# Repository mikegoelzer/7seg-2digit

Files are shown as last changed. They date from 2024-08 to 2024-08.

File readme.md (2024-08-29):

# Two Digit 7-Segment Display

This repository contains the design files for a 2-digit 7-segment display PMOD, modeled after the Digilent PMOD design but without a dual-row Dupont male header pinout. The display is designed for 3.3V operation and uses multiplexing to control both digits using only 8 GPIOs (7 for segments, one for left/right digit select).

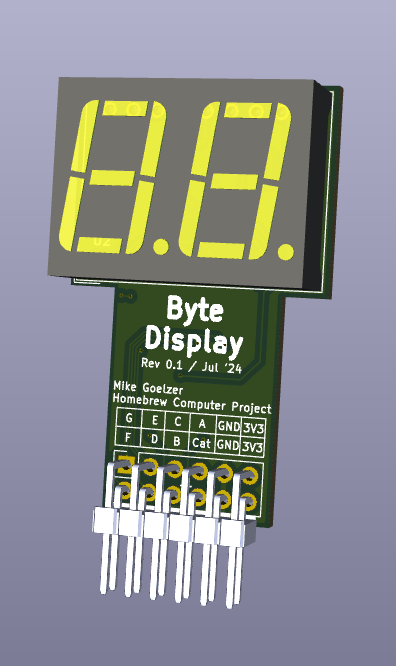
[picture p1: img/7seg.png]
3D Rendering of the 7-Segment Display printed circuit board


## Features

- 2-digit 7-segment display
- 3.3V operation
- Multiplexed design (8 GPIOs control both digits)

## Schematic

The schematic for this design can be found in the [docs/schematic.pdf](docs/schematic.pdf) file.

## Repository Structure

- `7Seg-Kicad/`: KiCad project files
- `bom/`: Excel sheet with Digikey/Mouser part numbers
- `docs/`: Documentation, including the schematic PDF
- `img/`: Images, including the 3D rendering
- `Parts/`: Parts imported into Kicad project

## Usage

This PCB can be used with any FPGA or microcontroller board, although it uses a non-standard pinout (for PMODs). The multiplexed design allows for efficient control of both digits using minimal GPIO pins.

## License

[GPLv3](https://www.gnu.org/licenses/gpl-3.0.en.html)

## Contributing

We welcome contributions to improve this design. Please feel free to submit issues or pull requests.

## Acknowledgements

This design is inspired by the [Digilent PMOD 7-segment display](https://digilent.com/shop/pmod-ssd-seven-segment-display/) but has been modified to fit a custom board and does not conform to the normal PMOD pinout.

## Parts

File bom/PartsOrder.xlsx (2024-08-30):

Desc | Parts | Actual Qty | Order Qty | Price | Subtotal | In basket? | Ordered? | Vendor URL | Mfgr PN | Notes | Digikey | Adafruit | Mouser | Sparkfun
Carrier Board: Hex Digits 7-segment
# of boards | 3
Bright red 2x7seg (DC56-11SURKWA) | U2 | 1 | 2 | 3.33 | $6.66 | ✅ | ❌ | https://www.digikey.com/en/products/detail/kingbright/DC56-11SURKWA/4098431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 | DC56-11SURKWA
NL27WZ14DFT2G dual inverter in SC-88 package | U1 | 1 | 3 | 0.32 | $0.96 | ✅ | ❌ | https://www.digikey.com/en/products/detail/onsemi/NL27WZ14DFT2G/920165 | NL27WZ14DFT2G |  | 1
820 resistors, 1206 3216 metric | R1-R8 | 8 | 0 | 0.1 | $0.00 | ✅ | ❌ | https://www.digikey.com/en/products/detail/yageo/RC1206JR-07820RL/729342 |  |  | 1
1k resistors, 1206 3216 metric | R1-R8 (alternate) | 8 | 24 | 0.035 | $0.84 | ✅ |  | https://www.digikey.com/en/products/detail/yageo/RC1206JR-071KL/729186
CAP CER 0.1UF 50V X7R 1206 | C1 | 1 | 0 | 0.19 | $0.00 | ✅ | ❌ | https://www.digikey.com/en/products/detail/yageo/CC1206KRX7R9BB104/302913 |  |  | 1
CAP 1206 25V 10 UF X7R | C2 | 1 | 0 | 0.51 | $0.00 | ✅ | ❌ | https://www.digikey.com/en/products/detail/yageo/cc1206kfx7r8bb106/20376253 |  |  | 1
2x6 right angle male 0.1" header pins | J1 | 1 | 2 | 0.37 | $0.74 | ✅ | ❌ | https://www.digikey.com/en/products/detail/adam-tech/PH2RA-12-UA/9830569 | PH2RA-12-UA |  | 1
Breadboard Breakout
# of boards | 4
6x2 0.1" female receptacle |  | 1 | 4 | 0.83 | $3.32 | ✅ | ❌ | https://www.digikey.com/en/products/detail/sullins-connector-solutions/PPPC062LFBN-RC/810246 | PPPC062LFBN-RC |  | 1
6x1 CONN HEADER VERT 6POS 2.54MM |  | 2 | 10 | 0.34 | $3.40 | ✅ | ❌ | https://www.digikey.com/en/products/detail/w%C3%BCrth-elektronik/61300611121/4846833 | 61300611121 |  | 1
Breadboard Breakout (ULX3S)
# of boards | 2
CONN HDR 40POS 0.1 GOLD PCB 2x20 female | J5 | 1 | 2 | 2.4 | $4.80 | ✅ | ❌ | https://www.digikey.com/en/products/detail/sullins-connector-solutions/PPPC202LFBN-RC/810259 | PPPC202LFBN-RC |  | 1
1x20 male pin headers 2.54mm | J6,J7 | 2 | 4 | 0.47 | $1.88 | ✅ | ❌ | https://www.digikey.com/en/products/detail/sullins-connector-solutions/PRPC020SFAN-RC/2775354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 | PRPC020SFAN-RC |  | 1

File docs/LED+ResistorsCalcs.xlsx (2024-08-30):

7 Segment Options
VCC |  | 3.30 | V
Part |  | Vf * | R | Current (mA) | ucd @ [current] |  | Notes | Digikey | Mouser | Datasheet
DC56-11GWA ** |  | 1.85 | 820 | 1.8 | 1980 |  | ** Used last time; too dim
* At specified current
New Parts & Resistors To Try
 | Color | Vf (at 4mA) | R | Current (mA) | ucd @ [current] | %age incr. brightness
~~DC56-11GWA~~ | ~~Green~~ | ~~1.85~~ | ~~360~~ | ~~4.0~~ | ~~4430.555556~~ | ~~123.7654321%~~ |  | ~~https://www.digikey.com/en/products/detail/kingbright/DC56-11GWA/3084377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 | ~~https://www.mouser.com/ProductDetail/Kingbright/DC56-11GWA?qs=sXafwHSx%252BU%252BFqc2jozM64A%3D%3D~~ | ~~https://www.mouser.com/datasheet/2/216/DC56_11GWA-3085178.pdf~~
DC56-11CGKWA | Bright green | 1.92 | 820 | 1.7 | 5890.243902 | 197.4870658% |  | Not available | Not available | https://www.kingbrightusa.com/images/catalog/SPEC/DC56-11CGKWA.pdf
DC56-11SURKWA | Bright red | 1.78 | 1000 | 1.5 | 12920 | 552.5252525% |  | https://www.digikey.com/en/products/detail/kingbright/DC56-11SURKWA/4098431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 | https://www.mouser.com/ProductDetail/Kingbright/DC56-11SURKWA?qs=2JU0tDl2GZ0YLerPzy77tw%3D%3D | https://www.mouser.com/datasheet/2/216/DC56-11SURKWA-245536.pdf
DC56-51SYKWA | Bright yellow | 1.90 | 1000 | 1.4 | 11900 | 501.010101% |  | Not available | Not available | https://www.mouser.com/datasheet/2/216/DC56-51SYKWA-246230.pdf
~~DC56-11EWA~~ | ~~Red~~ | ~~1.78~~ | ~~360~~ | ~~4.2~~ | ~~3377.777778~~ | ~~70.59483726%~~ |  | ~~https://www.digikey.com/en/products/detail/kingbright/DC56-11EWA/3084376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 | ~~https://www.mouser.com/ProductDetail/Kingbright/DC56-11EWA?qs=SO8VdE%2FgosGvL%2FnJcFkMow%3D%3D~~ | ~~https://www.mouser.com/datasheet/2/216/DC56-11EWA-43385.pdf~~

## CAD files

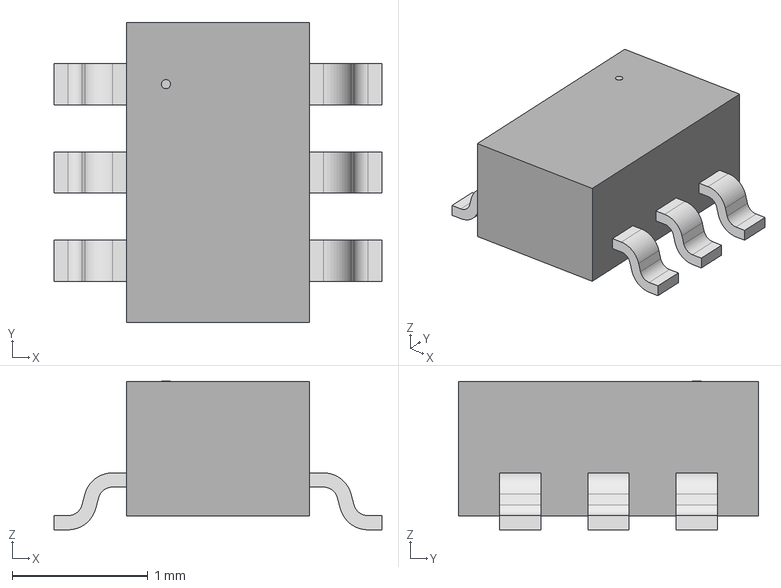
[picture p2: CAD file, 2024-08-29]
Parts/NL27WZ14DFT2G/SC70-6_ONS.step
2.41 x 2.21 x 1.09 mm

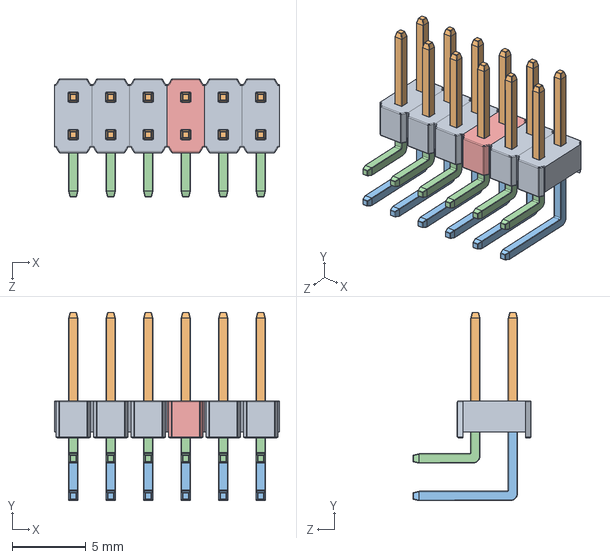
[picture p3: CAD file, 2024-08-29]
Parts/PH2RA-12-UA/PH2RA-12-UA.STEP
15.2 x 12.8 x 8.00 mm

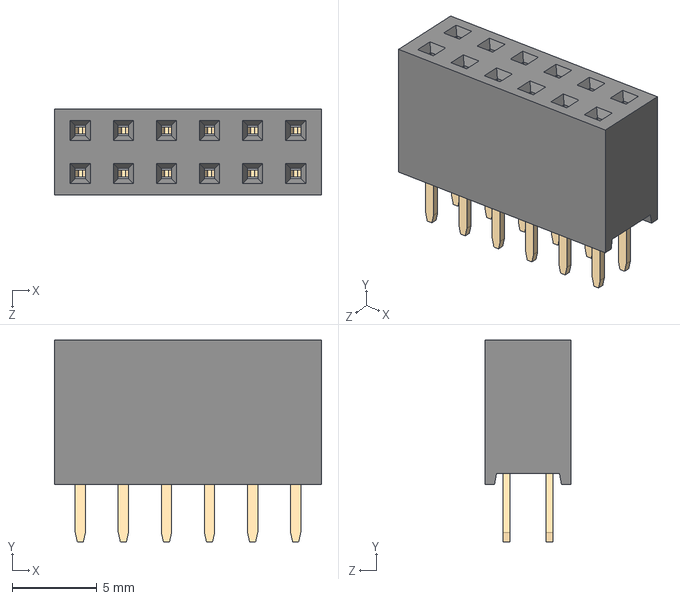
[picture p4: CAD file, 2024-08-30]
Parts/PPPC062LFBN-RC/PPPC062LFBN-RC.STEP
15.7 x 11.9 x 5.08 mm
2 row tin body_06
2 row tin pins x 6

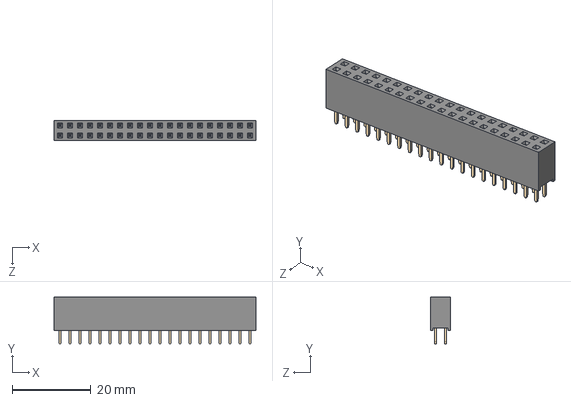
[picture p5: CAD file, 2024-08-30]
Parts/PPPC202LFBN-RC/PPPC202LFBN-RC.step
51.3 x 11.9 x 5.08 mm
2 row tin body_20
2 row tin pins x 20

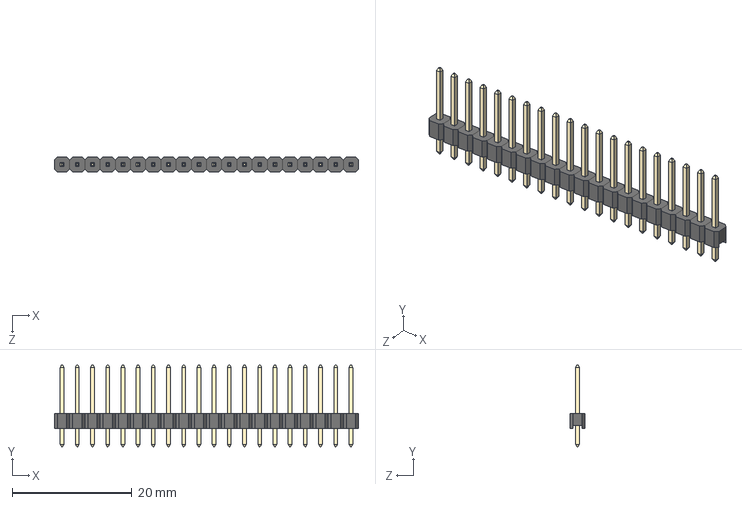
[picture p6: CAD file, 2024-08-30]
Parts/PRPC020SFAN-RC/PRPC020SFAN-RC.STEP
50.8 x 13.7 x 2.54 mm
1 row end bumps format x 20

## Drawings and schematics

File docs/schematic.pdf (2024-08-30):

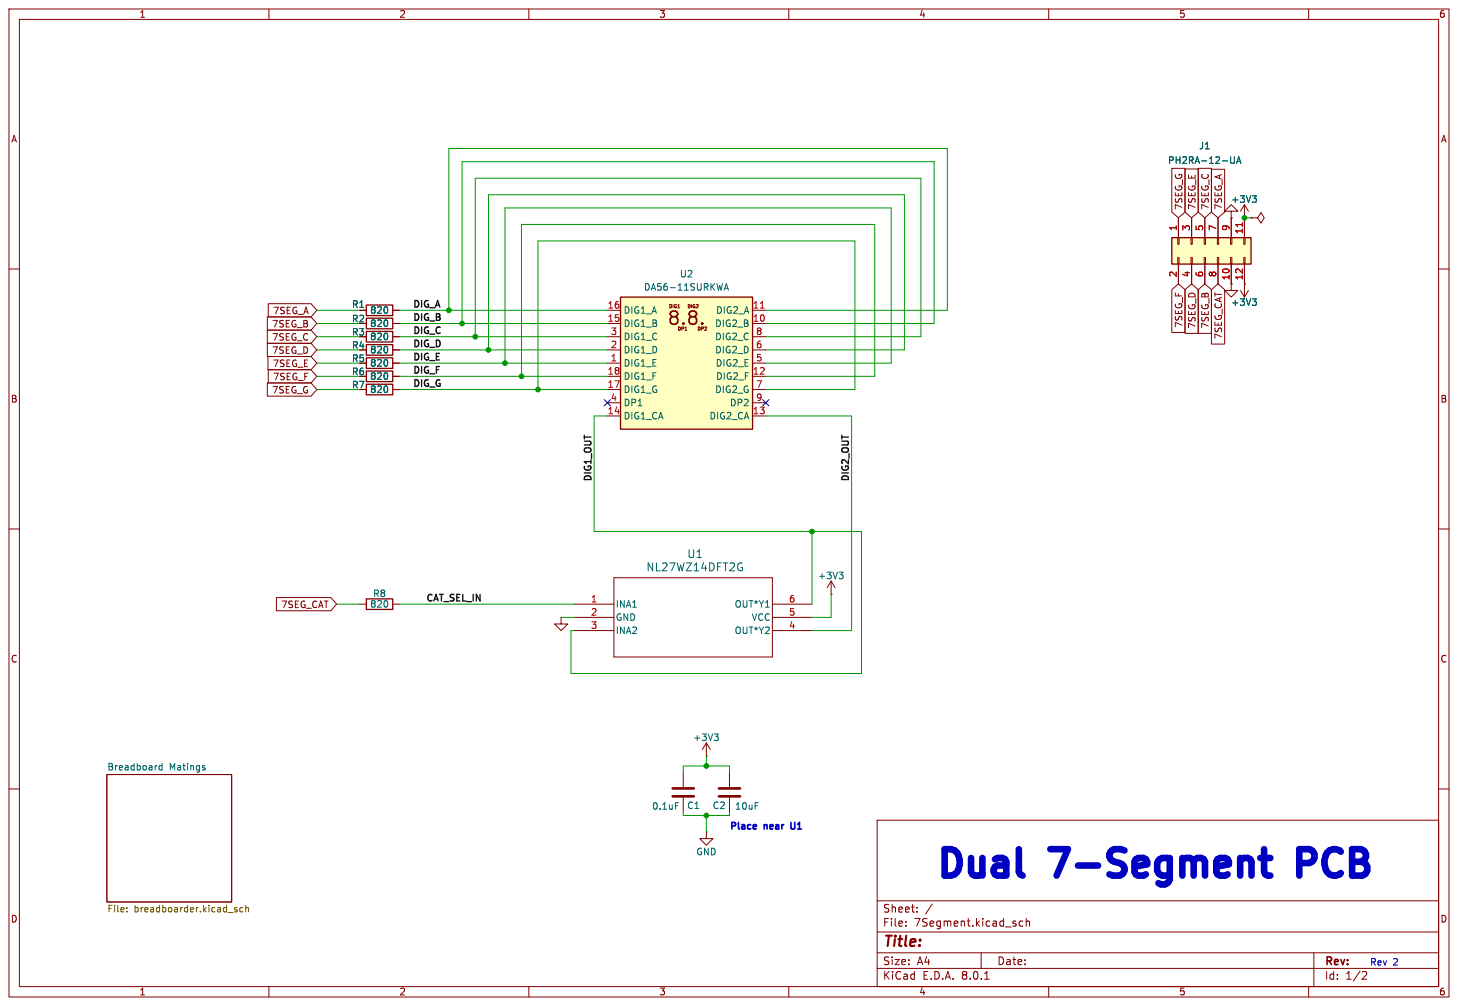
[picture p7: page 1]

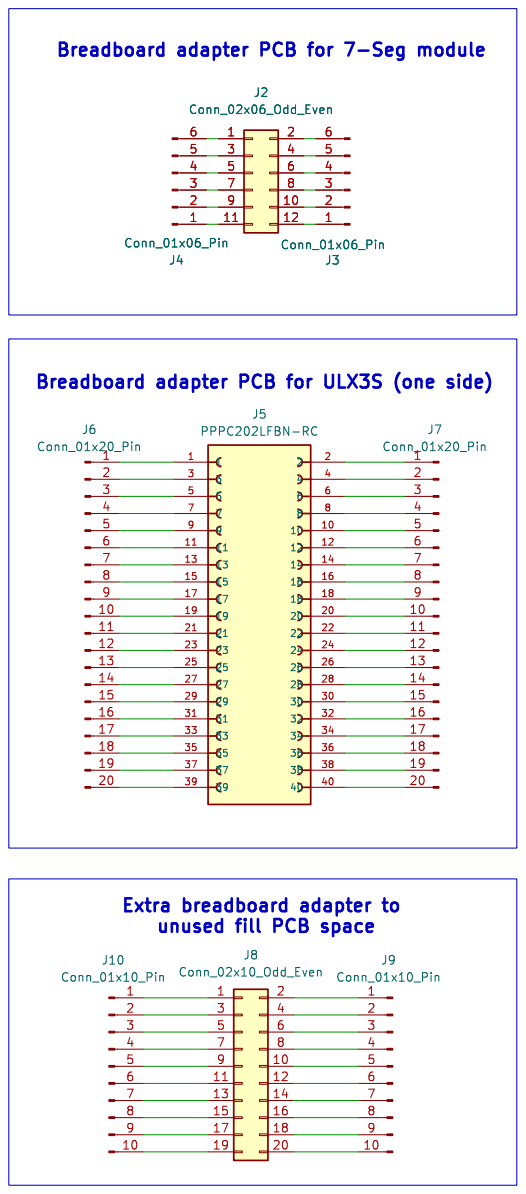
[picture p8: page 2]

Breadboard adapter PCB for ULX3S (one side) J4 Conn_01x06_Pin

Extra breadboard adapter to
unused fill PCB space

Adapter PCBs
(for plugging into breadboards)

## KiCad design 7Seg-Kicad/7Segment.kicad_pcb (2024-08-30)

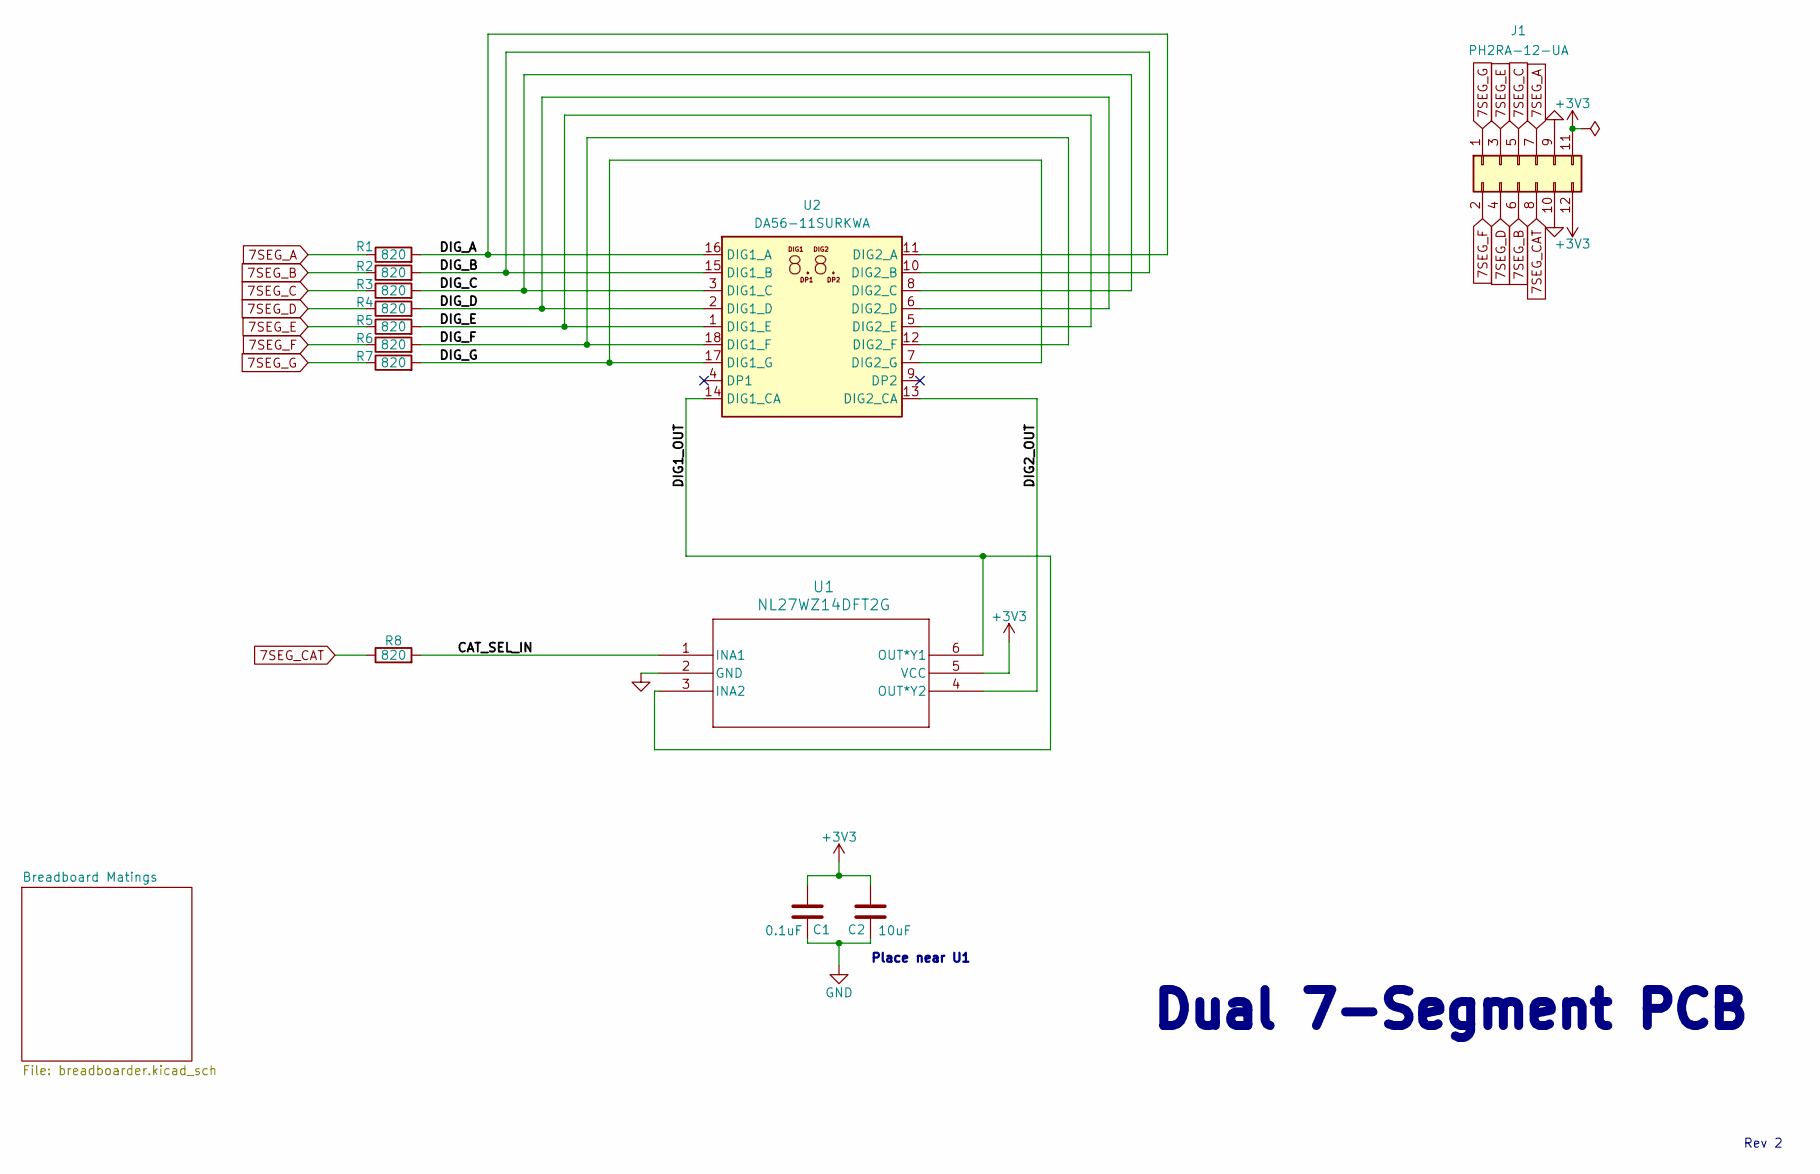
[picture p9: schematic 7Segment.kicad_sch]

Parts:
C1: 0.1uF; C_1206_3216Metric_Pad1.33x1.80mm_HandSolder
C2: 10uF; C_1206_3216Metric_Pad1.33x1.80mm_HandSolder
J1: PH2RA-12-UA; PinSocket_2x06_P2.54mm_Vertical; MPN PH2RA-12-UA
R1, R2, R3, R4, R5, R6, R7, R8: 820; R_1206_3216Metric_Pad1.42x1.75mm_HandSolder
U1: NL27WZ14DFT2G; SC70-6_ONS
U2: DA56-11SURKWA

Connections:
7SEG_A: J1.7, R1.1
7SEG_B: J1.6, R2.1
7SEG_C: J1.5, R3.1
7SEG_CAT: J1.8, R8.1
7SEG_D: J1.4, R4.1
7SEG_E: J1.3, R5.1
7SEG_F: J1.2, R6.1
7SEG_G: J1.1, R7.1
+3V3: C1.2, C2.2, J1.11, J1.12, U1.5 (VCC)
/CAT_SEL_IN: R8.2, U1.1 (INA1)
/DIG1_OUT: U1.3 (INA2), U1.6 (OUT*Y1), U2.14 (DIG1_CA)
/DIG2_OUT: U1.4 (OUT*Y2), U2.13 (DIG2_CA)
/DIG_A: R1.2, U2.11 (DIG2_A), U2.16 (DIG1_A)
/DIG_B: R2.2, U2.10 (DIG2_B), U2.15 (DIG1_B)
/DIG_C: R3.2, U2.3 (DIG1_C), U2.8 (DIG2_C)
/DIG_D: R4.2, U2.2 (DIG1_D), U2.6 (DIG2_D)
/DIG_E: R5.2, U2.1 (DIG1_E), U2.5 (DIG2_E)
/DIG_F: R6.2, U2.12 (DIG2_F), U2.18 (DIG1_F)
/DIG_G: R7.2, U2.7 (DIG2_G), U2.17 (DIG1_G)
GND: C1.1, C2.1, J1.9, J1.10, U1.2 (GND)

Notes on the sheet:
Place near U1
Rev 2
Dual 7-Segment PCB

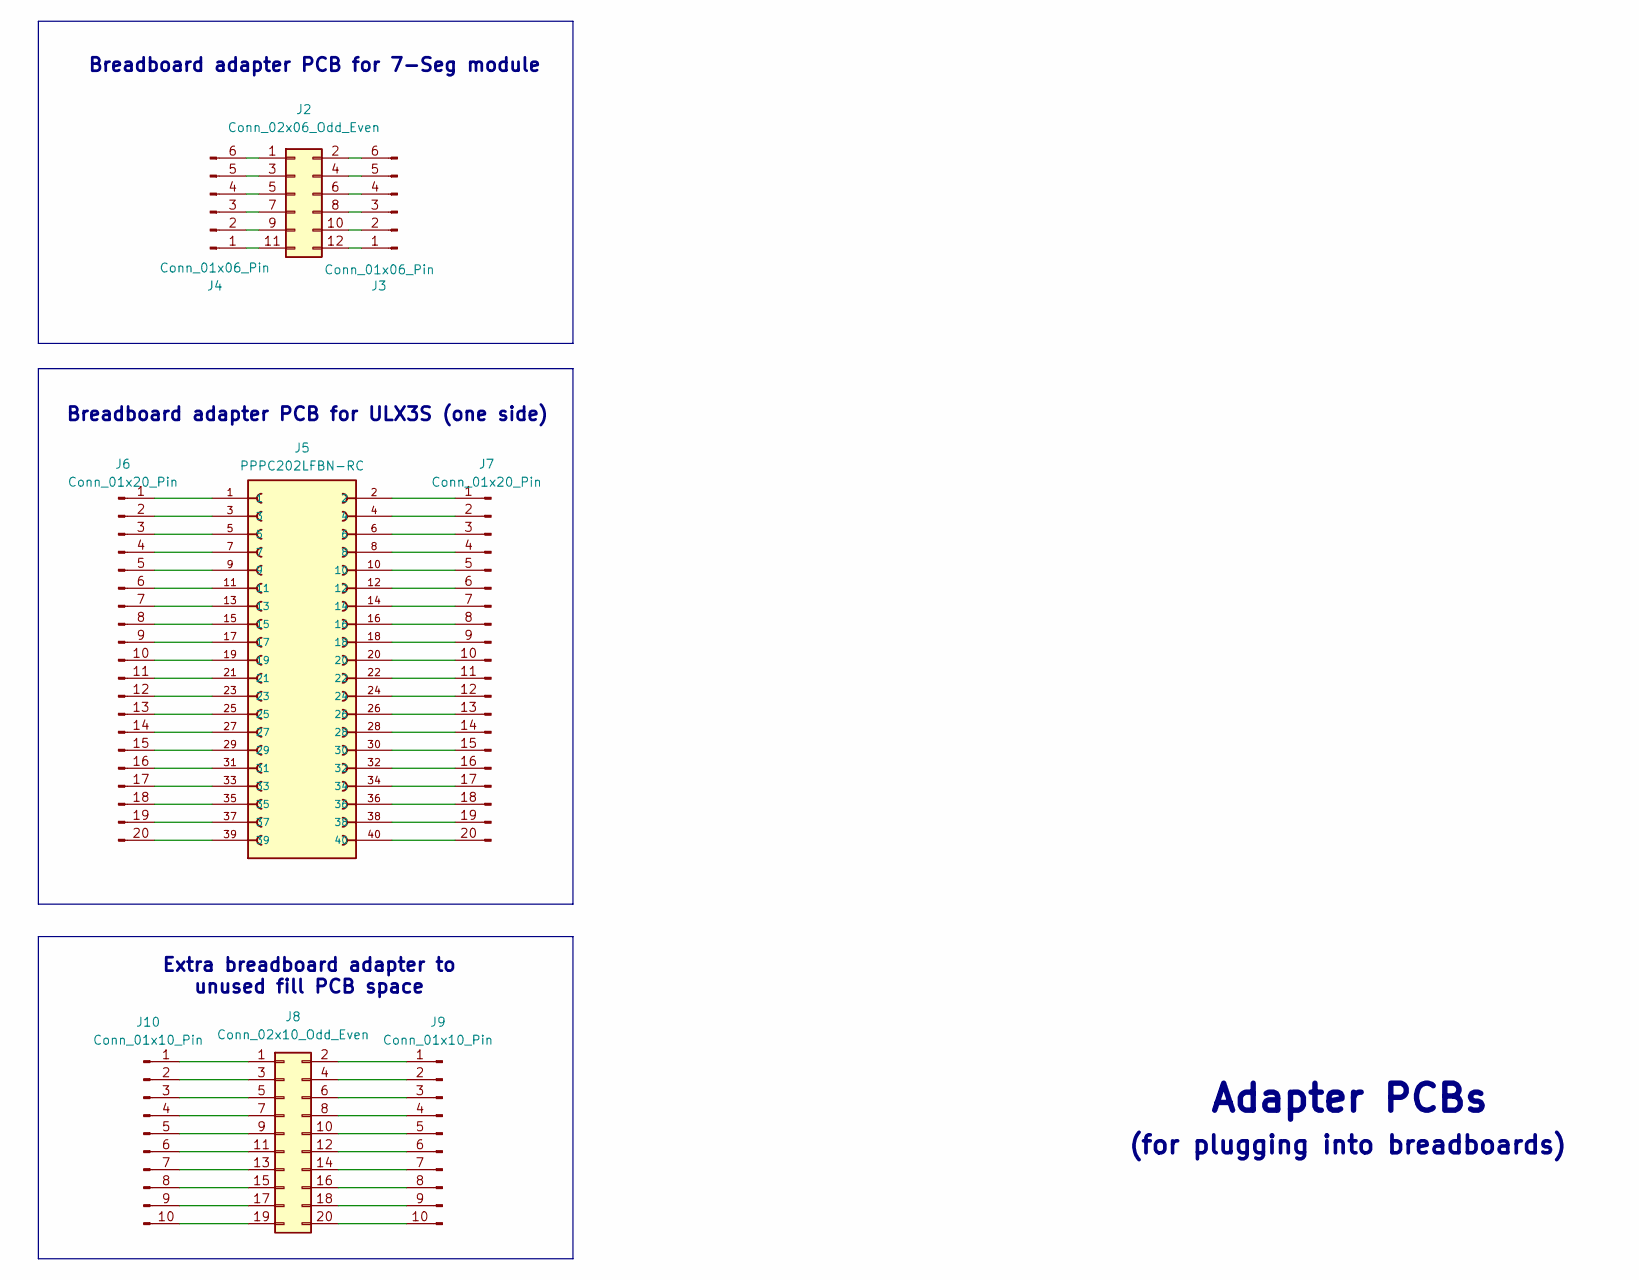
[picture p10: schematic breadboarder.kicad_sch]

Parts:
J2: Conn_02x06_Odd_Even; PinSocket_2x06_P2.54mm_Vertical
J3, J4: Conn_01x06_Pin; PinHeader_1x06_P2.54mm_Vertical
J5: PPPC202LFBN-RC; SULLINS_PPPC202LFBN-RC; PARTREV L
J6, J7: Conn_01x20_Pin; PinHeader_1x20_P2.54mm_Vertical
J8: Conn_02x10_Odd_Even; PinSocket_2x10_P2.54mm_Vertical
J9, J10: Conn_01x10_Pin; PinHeader_1x10_P2.54mm_Vertical

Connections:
unnamed: J2.1, J4.6
unnamed: J2.2, J3.6
unnamed: J2.3, J4.5
unnamed: J2.4, J3.5
unnamed: J2.5, J4.4
unnamed: J2.6, J3.4
unnamed: J2.7, J4.3
unnamed: J2.8, J3.3
unnamed: J2.9, J4.2
unnamed: J2.10, J3.2
unnamed: J2.11, J4.1
unnamed: J2.12, J3.1
unnamed: J5.1, J6.1
unnamed: J5.3, J6.2
unnamed: J5.5, J6.3
unnamed: J5.7, J6.4
unnamed: J5.9, J6.5
unnamed: J5.11, J6.6
unnamed: J5.13, J6.7
unnamed: J5.15, J6.8
unnamed: J5.17, J6.9
unnamed: J5.19, J6.10
unnamed: J5.21, J6.11
unnamed: J5.23, J6.12
unnamed: J5.25, J6.13
unnamed: J5.27, J6.14
unnamed: J5.29, J6.15
unnamed: J5.31, J6.16
unnamed: J5.33, J6.17
unnamed: J5.35, J6.18
unnamed: J5.37, J6.19
unnamed: J5.39, J6.20
unnamed: J5.2, J7.1
unnamed: J5.4, J7.2
unnamed: J5.6, J7.3
unnamed: J5.8, J7.4
unnamed: J5.10, J7.5
unnamed: J5.12, J7.6
unnamed: J5.14, J7.7
unnamed: J5.16, J7.8
unnamed: J5.18, J7.9
unnamed: J5.20, J7.10
unnamed: J5.22, J7.11
unnamed: J5.24, J7.12
unnamed: J5.26, J7.13
unnamed: J5.28, J7.14
unnamed: J5.30, J7.15
unnamed: J5.32, J7.16
unnamed: J5.34, J7.17
unnamed: J5.36, J7.18
unnamed: J5.38, J7.19
unnamed: J5.40, J7.20
unnamed: J8.2, J9.1
unnamed: J8.4, J9.2
unnamed: J8.6, J9.3
unnamed: J8.8, J9.4
unnamed: J8.10, J9.5
unnamed: J8.12, J9.6
unnamed: J8.14, J9.7
unnamed: J8.16, J9.8
unnamed: J8.18, J9.9
unnamed: J8.20, J9.10
unnamed: J8.1, J10.1
unnamed: J8.3, J10.2
unnamed: J8.5, J10.3
unnamed: J8.7, J10.4
unnamed: J8.9, J10.5
unnamed: J8.11, J10.6
unnamed: J8.13, J10.7
unnamed: J8.15, J10.8
unnamed: J8.17, J10.9
unnamed: J8.19, J10.10

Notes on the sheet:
(for plugging into breadboards)
Adapter PCBs
Breadboard adapter PCB for 7-Seg module
Breadboard adapter PCB for ULX3S (one side)
Extra breadboard adapter to unused fill PCB space

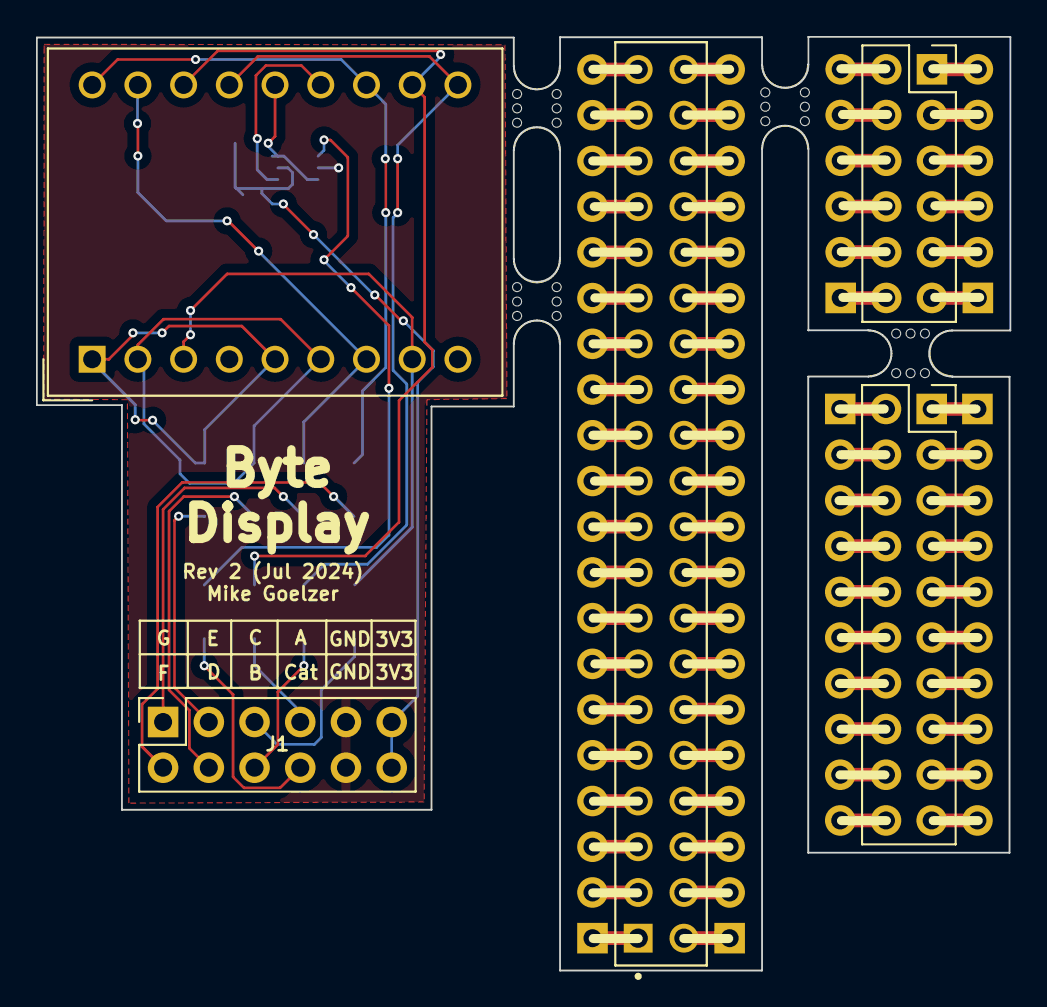
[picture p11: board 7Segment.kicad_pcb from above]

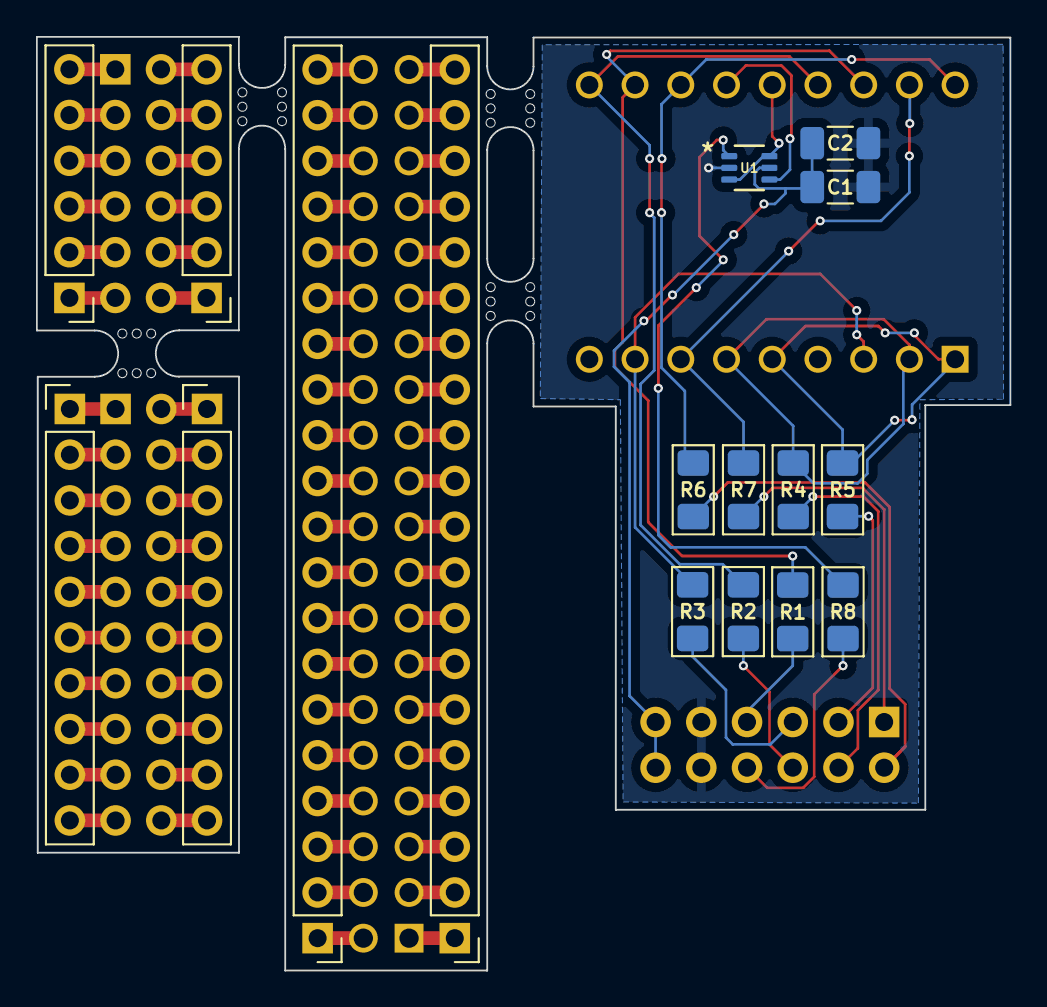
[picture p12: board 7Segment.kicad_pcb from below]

Board: 2 copper layers, 54.1 x 51.9 mm, 26 parts (17 on the bottom side), 92 nets.

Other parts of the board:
mouse-bite-2.54mm-slot, mouse-bite-2.54mm-slot#2, mouse-bite-2.54mm-slot#3, mouse-bite-2.54mm-slot#4: VAL**; mouse-bite-2.54mm-slot

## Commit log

2024-08-29 revision 0.1
    [7Segment.kicad_pcb, 7Segment.kicad_sch, PH2RA-12-UA.STEP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]
2024-08-30 Revision 2 final
    [7Segment.kicad_pcb, 7Segment.kicad_sch, LED+ResistorsCalcs.xlsx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]
2024-08-30 correct part description
    [7Segment.kicad_sch]
2024-08-30 add drill slot to comply with oshpark reqs
    [7Segment.kicad_pcb]
